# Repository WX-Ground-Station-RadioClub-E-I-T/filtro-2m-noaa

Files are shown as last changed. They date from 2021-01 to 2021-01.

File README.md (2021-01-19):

# Filtro-2m-NOAA

Filtro paso banda para banda de radioaficionados de 2m y satélites NOAA/Meteor, con alto rechazo en zona de frecuencias de radiodifusión FM.

## Especificaciones

- Tipo: Tchebyshev

- Impedancia entrada/salida: 50 Ohm

- Frecuencia de corte inferior (3dB): 125MHz

- Frecuencia de corte superior (3dB): 150MHz

- Pérdidas de inserción: 1dB máx.

- S11 en banda de paso: -15dB máx.

- Rechazo banda radiodifusión FM: 45dB (min)

- Rechazo banda radiodifusión TV: 50dB (min)

## Materiales

| Componente | Valor | Métrica |
|:---:|:-----:|:---:|
| C1 |  10pF | 0805  |
| C2 | 2,7pF | 0805  |
| C3 | 2,2pF | 0603  |
| C4 |  10pF | 0805  |
| C5 | 1,5pF | 0603  |
| C6 |  10pF | 0805  |
| C7 | 2,2pF | 0603  |
| C8 | 2,7pF | 0805  |
| C9 |  10pF | 0805  |
| L1 | 100nH | 0603  |
| L2 | 100nH | 0603  |
| L3 | 100nH | 0603  |
| L4 | 100nH | 0603  |
| L5 | 100nH | 0603  |
|  Conector  |  SMA  | - |

## Resultados

Parmámetros S:

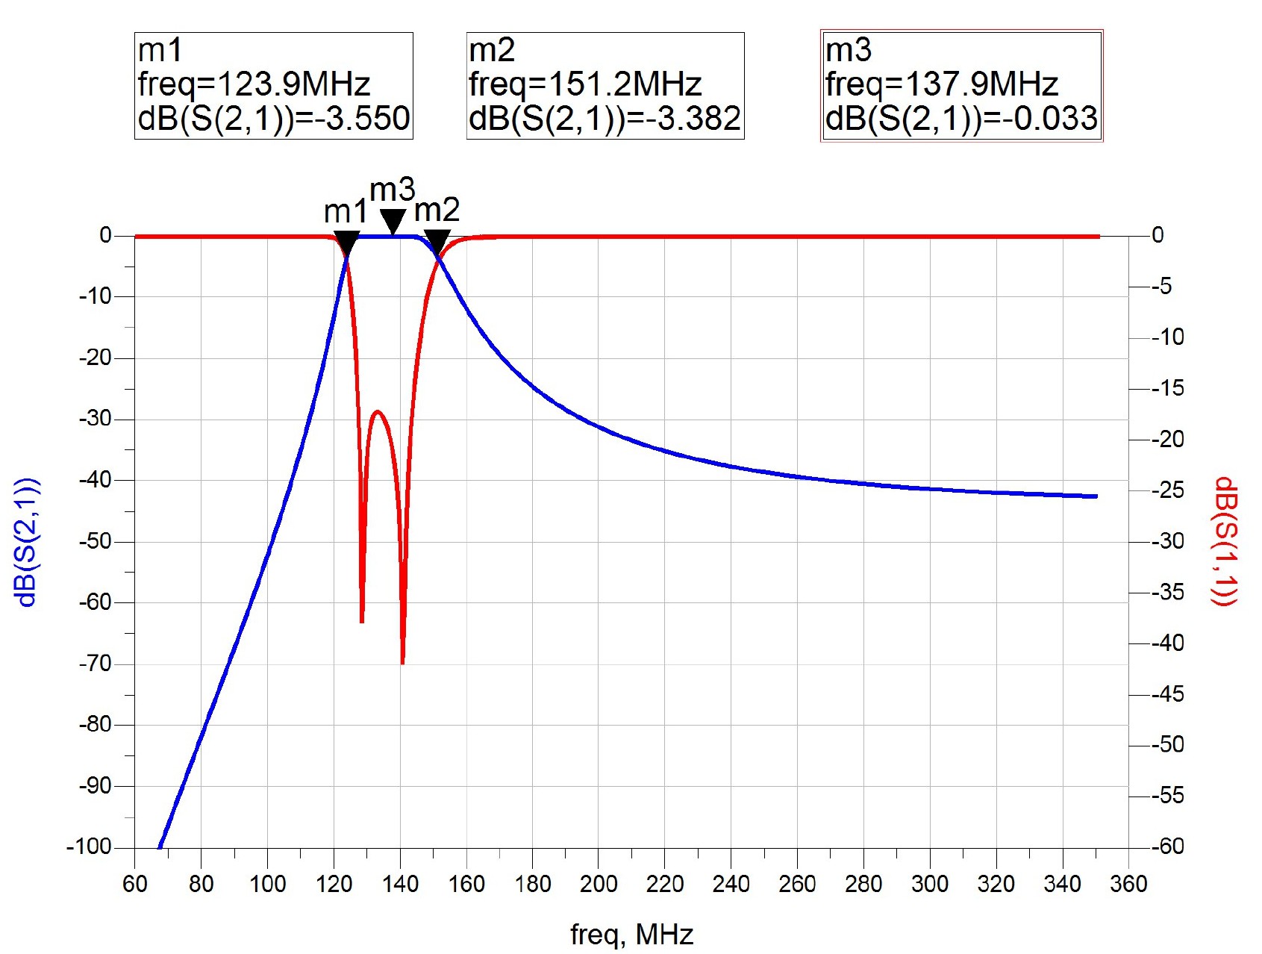
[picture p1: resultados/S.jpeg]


Esquemático: 

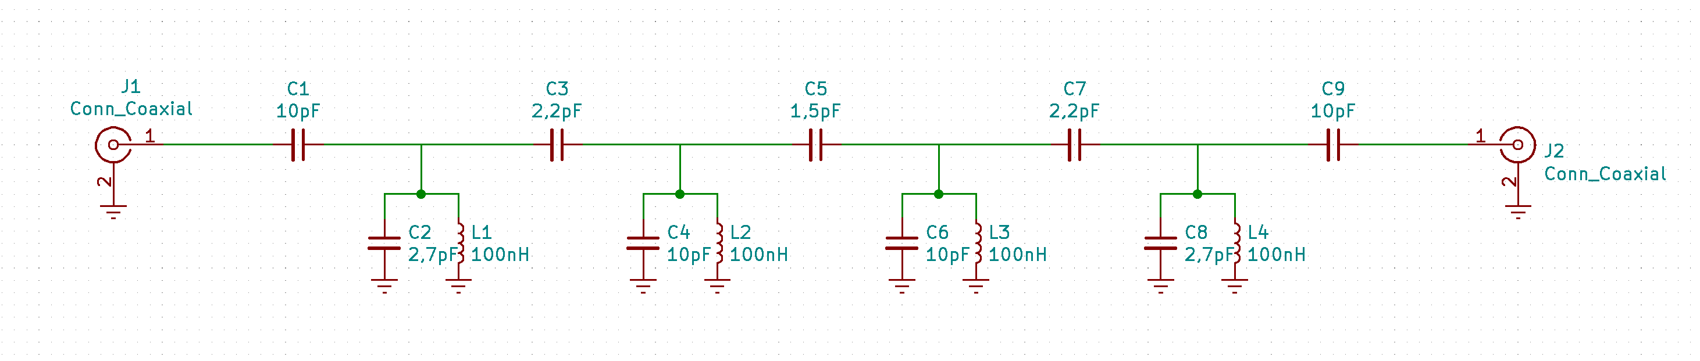
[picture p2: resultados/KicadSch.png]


Modelo 3D:

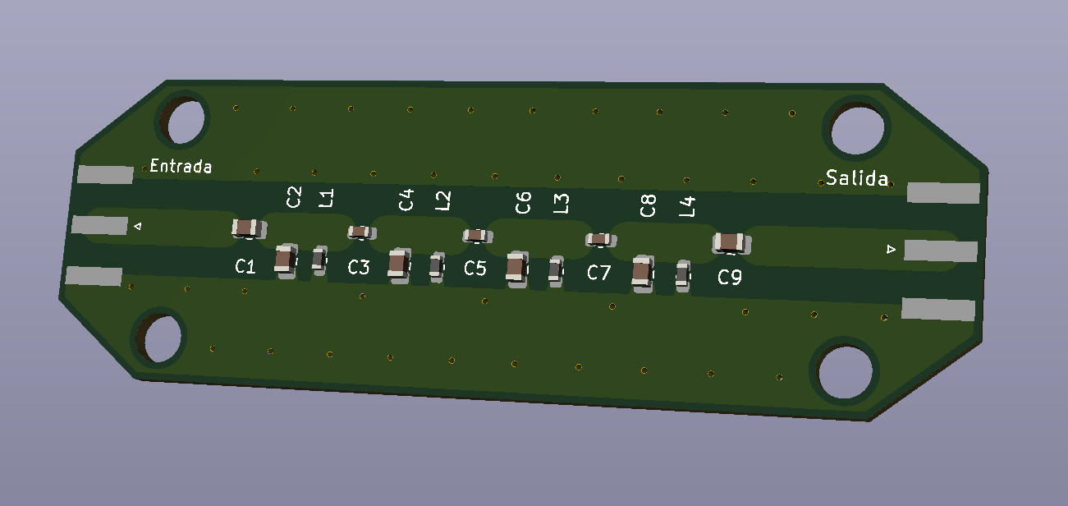
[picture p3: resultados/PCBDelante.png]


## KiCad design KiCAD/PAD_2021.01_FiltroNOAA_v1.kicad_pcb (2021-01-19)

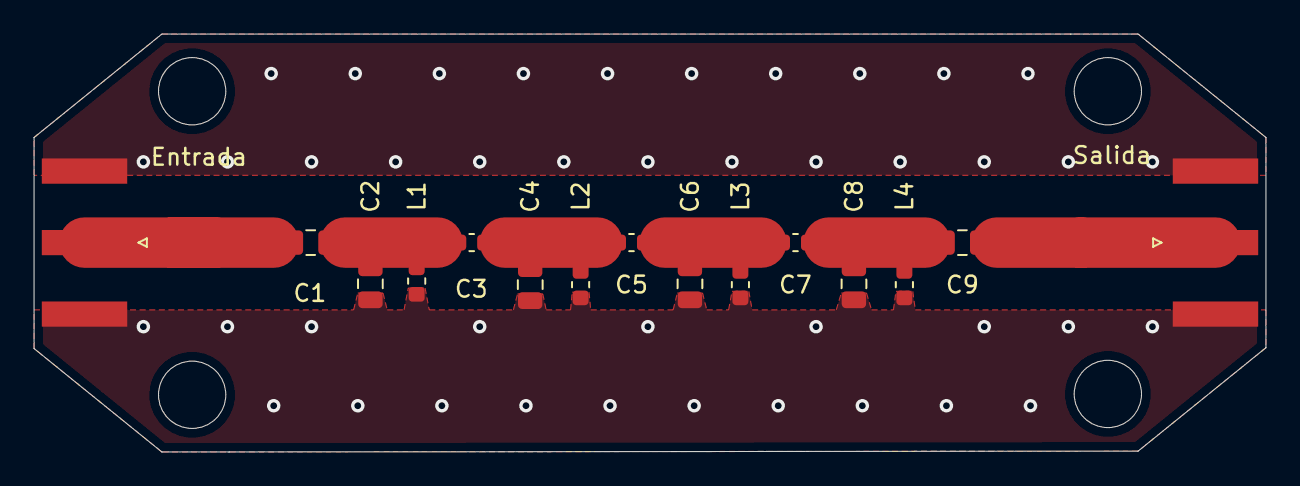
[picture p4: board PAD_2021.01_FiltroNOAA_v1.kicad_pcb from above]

Board: 2 copper layers, 73.2 x 24.9 mm, 15 parts (0 on the bottom side), 7 nets.

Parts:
C1, C4, C6, C9: 10pF; C_0805_2012Metric
C2, C8: 2,7pF; C_0805_2012Metric
C3, C7: 2,2pF; C_0603_1608Metric
C5: 1,5pF; C_0603_1608Metric
Entrada: Conn_Coaxial; SMA_Amphenol_132289_EdgeMount
L1, L2, L3, L4: 100nH; L_0603_1608Metric
Salida: Conn_Coaxial; SMA_Amphenol_132289_EdgeMount

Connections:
Earth: C2.2, C4.2, C6.2, C8.2, Entrada.2, L1.2, L2.2, L3.2, L4.2, Salida.2
unnamed: C1.1, C2.1, C3.2, L1.1
unnamed: C1.2, Entrada.1
unnamed: C3.1, C4.1, C5.2, L2.1
unnamed: C5.1, C6.1, C7.2, L3.1
unnamed: C7.1, C8.1, C9.2, L4.1
unnamed: C9.1, Salida.1

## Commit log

2021-01-19 Subir archivos a 'KiCAD'
    [PAD_2021.01_FiltroNOAA_v1.kicad_pcb, PAD_2021.01_FiltroNOAA_v1.sch]
2021-01-19 Subir archivos a 'ADS'
    [dds.cfg, de_sim.cfg, hpeesofsim.cfg]
2021-01-19 Subir archivos a 'ADS/PAD_2021.01_FiltroRadio_lib/%Filtro_tb/schematic'
2021-01-19 Subir archivos a 'ADS/PAD_2021.01_FiltroRadio_lib/filtro_teorico/schematic'
2021-01-19 Subir archivos a 'Gerbers'
    [PAD_2021.01_FiltroNOAA_v1-B_Cu.gbr, PAD_2021.01_FiltroNOAA_v1-B_Mask.gbr, PAD_2021.01_FiltroNOAA_v1-B_Paste.gbr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]
